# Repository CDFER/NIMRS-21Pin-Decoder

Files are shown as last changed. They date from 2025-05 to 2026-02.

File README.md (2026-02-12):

# NIMRS-21Pin-Decoder

PCB Render

A miniature DCC decoder for model railways featuring an ESP32-S3 microcontroller, designed to fit standard 21-pin sockets. Includes motor control, sound output, and lighting control in a 30x15.5mm footprint (following NMRA spec).

I don't quite have the time to work on this project at the momemnt but Kyle (ProjectInitiative) is starting to work on firmware for this board. You can follow the progress here: [https://github.com/ProjectInitiative/NIMRS-Firmware](https://github.com/ProjectInitiative/NIMRS-Firmware)

## Features

- **Compact Design**: 30mm × 15.5mm × 1.0mm 4-layer PCB
- **Power Management**: Dual TPS63070 buck-boost converters for stable 9V (motor) and 3.3V (logic) supplies
- **Quiet Operation**: DRV8213 motor driver with real-time adjustable off-time current regulation
- **Audio System**: MAX98357A I2S amplifier driving 4-8Ω speaker
- **Wireless Capable**: U.FL antenna connector for ESP32-S3's Wi-Fi
- **DCC Compatibility**: Handles ~15V square wave AC input

## Technical Specifications

### Core Components

- **MCU**: ESP32-S3FN8 (240MHz dual-core, 8MB embedded flash)
- **Motor Driver**: [TI DRV8213](https://www.ti.com/lit/ds/symlink/drv8213.pdf)
- **Audio Amplifier**: [MAX98357A](https://www.analog.com/media/en/technical-documentation/data-sheets/MAX98357A-MAX98357B.pdf)
- **Power Regulation**: Dual [TPS63070](http://www.ti.com/lit/ds/symlink/tps63070.pdf) buck-boost converters

### PCB Stackup

1. Top Layer: Signals with GND pour
2. Inner 1: Full GND plane
3. Inner 2: Signals with 3V3 pour
4. Bottom Layer: GND plane with sparse signals

PCB Layers

## Design Highlights

- Single-sided assembly and 0.3/0.4mm for cost efficiency
- Optimized ground planes for EMI reduction
- Decoupling buck-boost for stable motor PWM operation
- WiFi + BT support with U.FL antenna

## Getting Started

1. Clone the repository:

   ```bash
   git clone https://github.com/CDFER/NIMRS-21Pin-Decoder.git
   ```

2. Open in KiCad v9.0+
3. Review design files:
   - [Interactive PCB Viewer](https://kicanvas.org/?github=https%3A%2F%2Fgithub.com%2FCDFER%2FNIMRS-21Pin-Decoder)
   - [Schematic](Images/Schematic.avif)
   - [PCB Layout](Images/PCB-All-Layers.avif)

## Repository Structure

```
├── Custom_Footprints.pretty  # Custom component footprints
├── Datasheets               # Component technical documents
├── Images                   # PCB visuals and renders
├── LICENSE
└── README.md
```

For those wondering the 21-Pin decoder socket uses a 1.27mm, 22Pin back entry connector and I am using the ```BD050-22-A-0-0500-L-D``` from GCT (the CAD file, footprint and symbol can be found in the custom footprints library I have made).

Top View

## License

MIT License - See [LICENSE](LICENSE) for details.

## Contributing

Pull requests welcome! Please discuss major changes via issues first.

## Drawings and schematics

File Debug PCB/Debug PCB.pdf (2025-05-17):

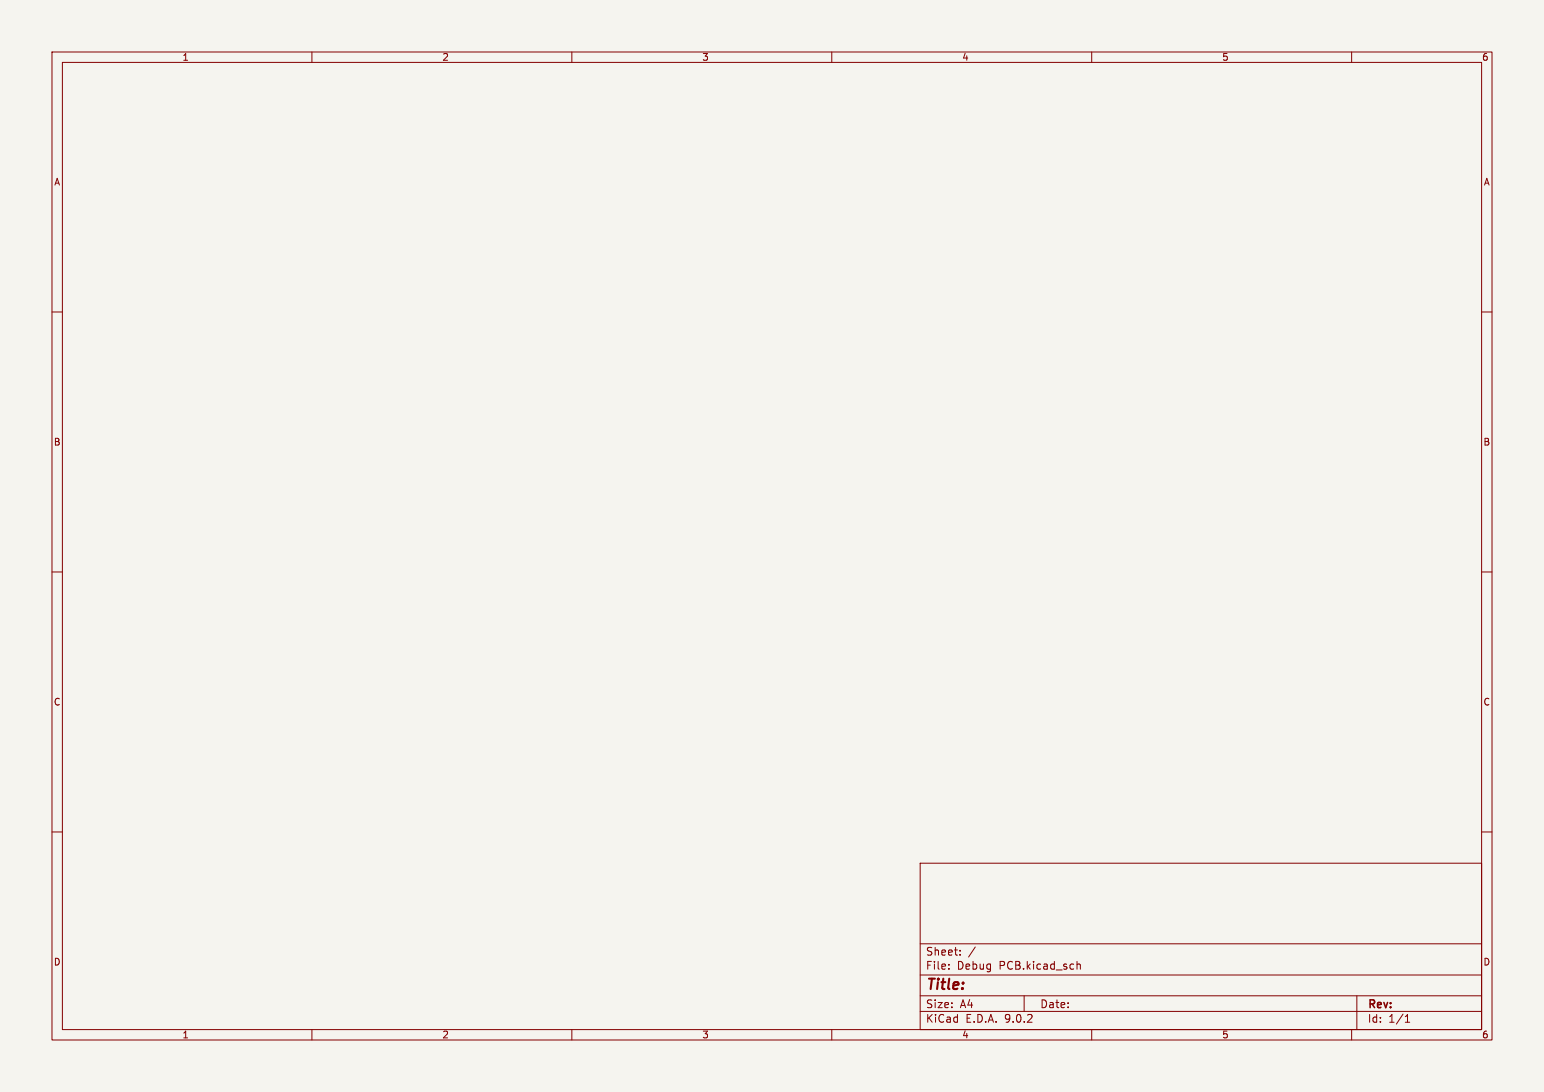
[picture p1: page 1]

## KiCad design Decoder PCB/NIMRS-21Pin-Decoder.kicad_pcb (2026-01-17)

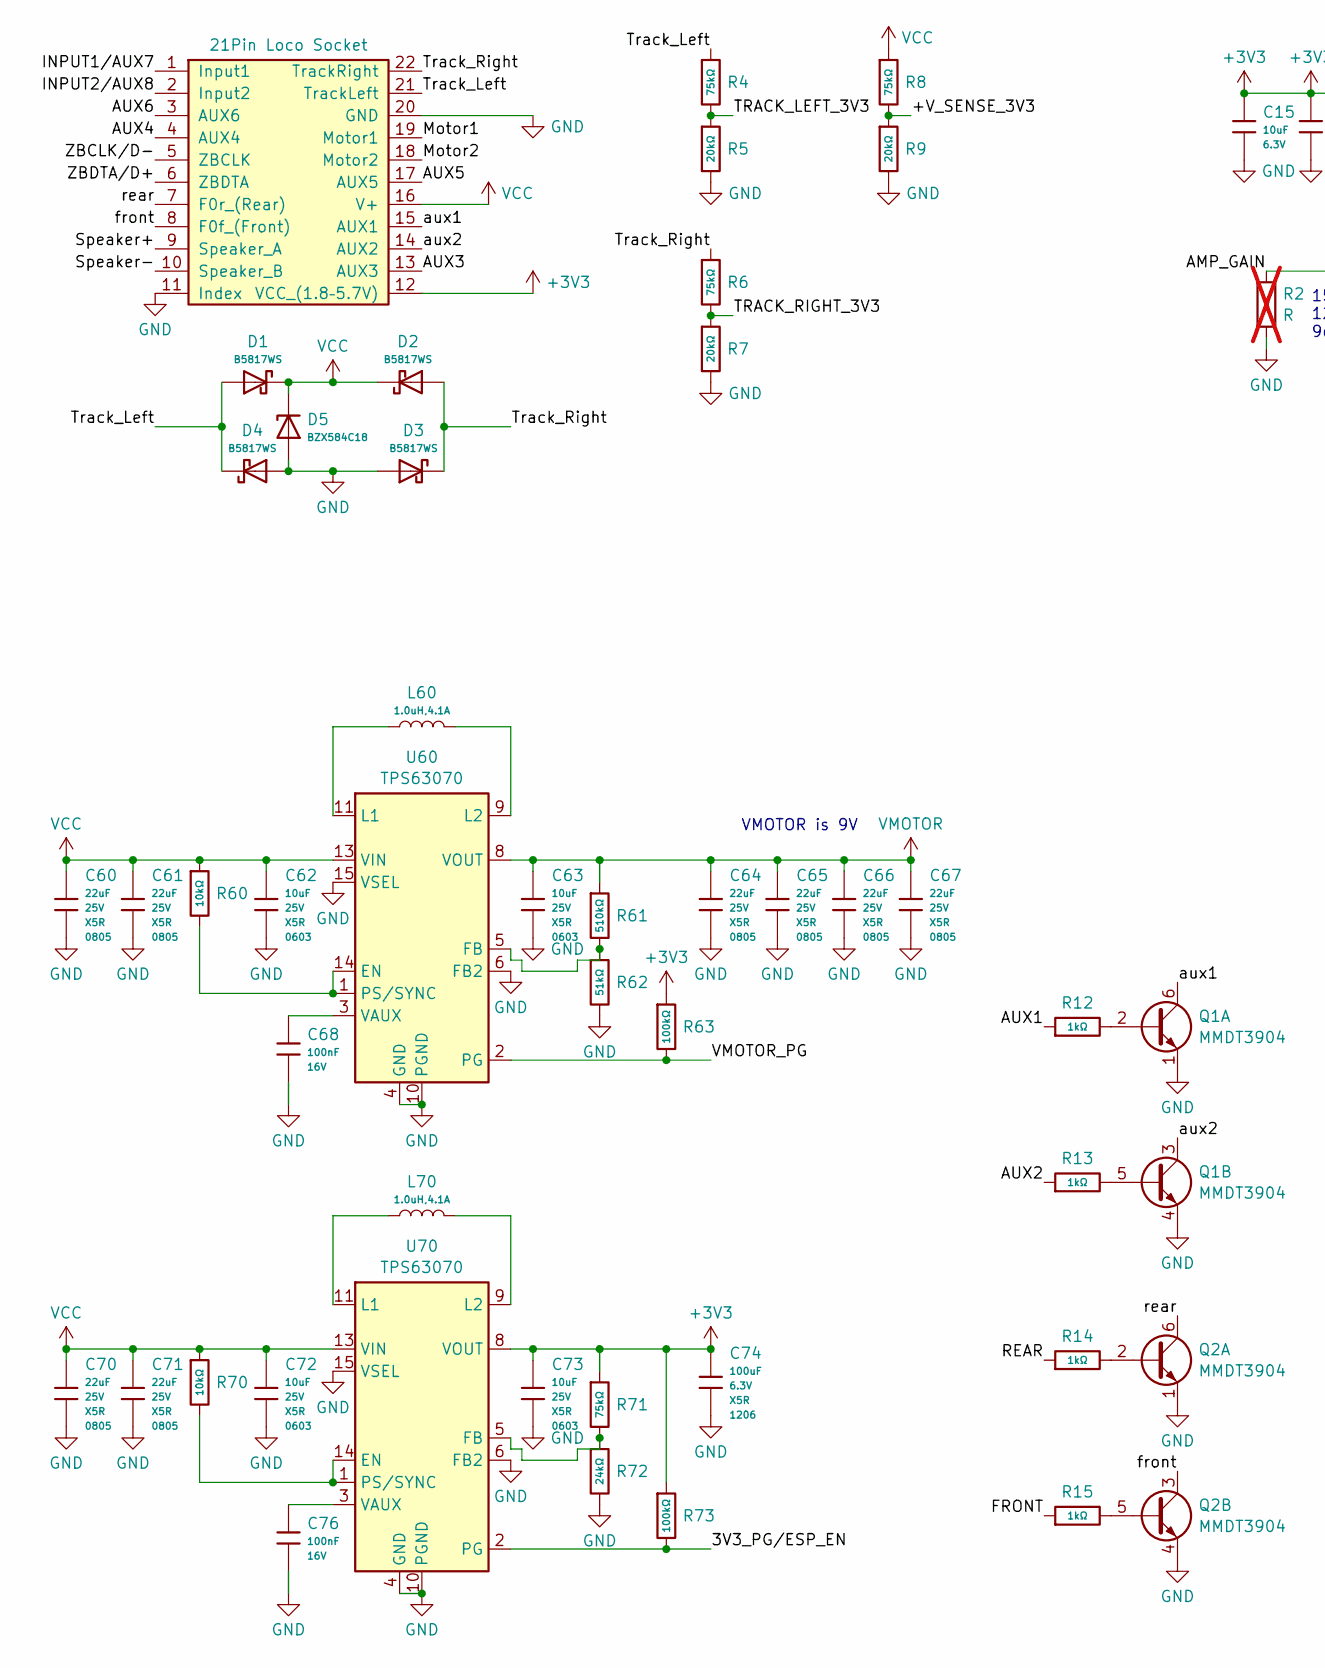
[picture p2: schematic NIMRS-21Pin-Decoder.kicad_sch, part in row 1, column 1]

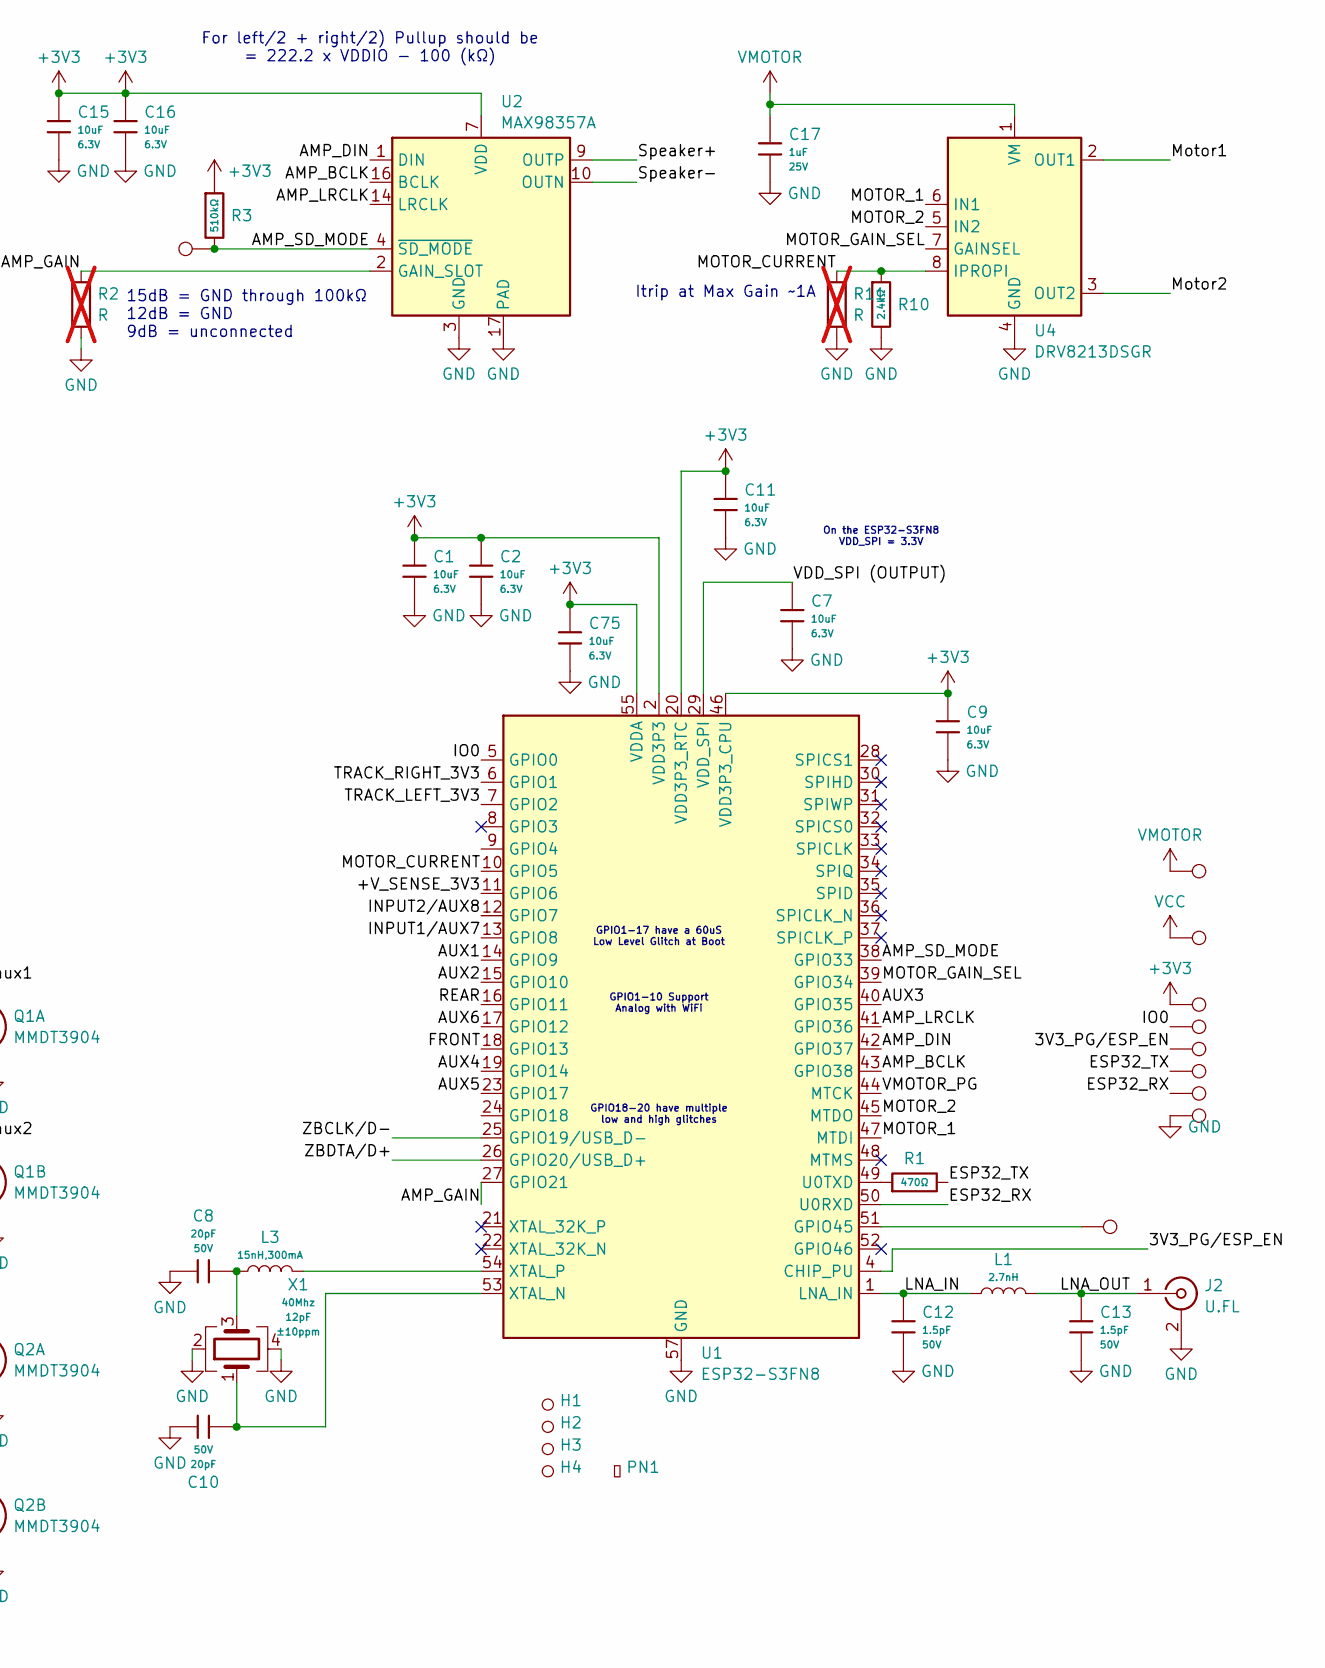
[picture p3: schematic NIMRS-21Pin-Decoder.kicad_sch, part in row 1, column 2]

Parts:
C1, C2, C7, C9, C11, C15, C16, C75: 10uF; C_0402; Voltage Rated 6.3V; Tolerance ±20%; Part CL05A106MQ5NUNC; LCSC C15525
C8, C10: 20pF; C_0402; Voltage Rated 50V; Tolerance ±5%; Part 0402CG200J500NT; LCSC C1554
C12, C13: 1.5pF; C_0402; Voltage Rated 50V; Part 0402CG1R5C500NT; LCSC C1552
C17: 1uF; C_0402; Voltage Rated 25V; Tolerance ±10%; Part CL05A105KA5NQNC; LCSC C52923
C60, C61, C64, C65, C66, C67, C70, C71: 22uF; C_0805; Voltage Rated 25V; Tolerance ±20%; Part CL21A226MAQNNNE; LCSC C45783
C62, C63, C72, C73: 10uF; C_0603; Voltage Rated 25V; Tolerance ±20%; Part CL10A106MA8NRNC; LCSC C96446
C68, C76: 100nF; C_0402; Voltage Rated 16V; Tolerance ±10%; Part CL05B104KO5NNNC; LCSC C1525
C74: 100uF; C_1206; Voltage Rated 6.3V; Tolerance ±20%; Part CL31A107MQHNNNE; LCSC C15008
D1, D2, D3, D4: B5817WS; D_SOD-323; Forward Voltage (Vf@If) 450mV@1.0A; Reverse Voltage (Vr) 20V; Part B5817WS; LCSC C7420329
D5: BZX584C18; D_SOD-523; Part BZX584C18; LCSC C22395581
H1, H2, H3, H4: Hole_Tooling_JLCPCB
J1: 21Pin Loco Socket; BD050-22-A-0-0500-L-D; LCSC C7219764
J2: U.FL; IPEX-SMD_BWIPX-1-001E; LCSC C5137195
L1: 2.7nH; L_0402; Part LQG15HS2N7S02D; LCSC C77108
L3: 15nH,300mA; L_0402; Tolerance ±5%; Part SDCL1005C15NJTDF; LCSC C27143
L60, L70: 1.0uH,4.1A; IND-SMD_L2.0-W1.6-B; Tolerance ±20%; Part FTC201610S1R0MBCA; LCSC C5832342
PN1: Part_Num_JLCPCB
Q1, Q2: MMDT3904; SOT-363_SC-70-6; Part MMDT3904; LCSC C41375125
R1: 470Ω; R_0402; Overload Voltage (Max) 50V; Tolerance ±1%; Part 0402WGF4700TCE; LCSC C25117
R2, R11: R; R_0805_2012Metric_Pad1.20x1.40mm_HandSolder; not fitted
R3, R61: 510kΩ; R_0402; Overload Voltage (Max) 50V; Tolerance ±1%; Part 0402WGF5103TCE; LCSC C11616
R4, R6, R8, R71: 75kΩ; R_0402; Overload Voltage (Max) 50V; Tolerance ±1%; Part 0402WGF7502TCE; LCSC C25798
R5, R7, R9: 20kΩ; R_0402; Overload Voltage (Max) 50V; Tolerance ±1%; Part 0402WGF2002TCE; LCSC C25765
R10: 2.4kΩ; R_0402; Overload Voltage (Max) 50V; Tolerance ±1%; Part 0402WGF2401TCE; LCSC C25882
R12, R13, R14, R15: 1kΩ; R_0402; Overload Voltage (Max) 50V; Tolerance ±1%; Part 0402WGF1001TCE; LCSC C11702
R60, R70: 10kΩ; R_0402; Overload Voltage (Max) 50V; Tolerance ±1%; Part 0402WGF1002TCE; LCSC C25744
R62: 51kΩ; R_0402; Overload Voltage (Max) 50V; Tolerance ±1%; Part 0402WGF5102TCE; LCSC C25794
R63, R73: 100kΩ; R_0402; Overload Voltage (Max) 50V; Tolerance ±1%; Part 0402WGF1003TCE; LCSC C25741
R72: 24kΩ; R_0402; Overload Voltage (Max) 50V; Tolerance ±1%; Part 0402WGF2402TCE; LCSC C25769
TP1, TP2, TP3, TP4, TP5, TP6, TP7, TP8, TP9, TP10: Test Point; TestPoint_Pad_D1.0mm
U1: ESP32-S3FN8; QFN-56-1EP_7x7mm_P0.4mm_EP4x4mm_ThermalVias; LCSC C2913196
U2: MAX98357A; TQFN-16-1EP_3x3mm_P0.5mm_EP1.23x1.23mm; LCSC C910544
U4: DRV8213DSGR; WSON-8-1EP_2x2mm_P0.5mm_EP0.9x1.6mm; LCSC C22407186
U60, U70: TPS63070; RNM0015A; LCSC C109322
X1: 40Mhz; Crystal_SMD_2016-4Pin_2.0x1.6mm; Tolerance ±10ppm; LCSC C20885029

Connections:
+3V3: C1.1, C2.1, C9.1, C11.1, C15.1, C16.1, C73.1, C74.1, C75.1, J1.12 (VCC_(1.8–5.7V)), R3.1, R63.1, R71.1, R73.1, TP2.1, U1.2 (VDD3P3), U1.3 (VDD3P3), U1.20 (VDD3P3_RTC), U1.46 (VDD3P3_CPU), U1.55 (VDDA), U1.56 (VDDA), U2.7 (VDD), U2.8 (VDD), U70.8 (VOUT)
/3V3_PG/ESP_EN: R73.2, TP3.1, U1.4 (CHIP_PU), U70.2 (PG)
/+V_SENSE_3V3: R8.2, R9.1, U1.11 (GPIO6)
/AMP_BCLK: U1.43 (GPIO38), U2.16 (BCLK)
/AMP_DIN: U1.42 (GPIO37), U2.1 (DIN)
/AMP_GAIN: R2.1, U1.27 (GPIO21), U2.2 (GAIN_SLOT)
/AMP_LRCLK: U1.41 (GPIO36), U2.14 (LRCLK)
/AMP_SD_MODE: R3.2, TP8.1, U1.38 (GPIO33), U2.4 (~SD_MODE)
/AUX1: R12.1, U1.14 (GPIO9)
/AUX2: R13.1, U1.15 (GPIO10)
/AUX3: J1.13 (AUX3), U1.40 (GPIO35)
/AUX4: J1.4 (AUX4), U1.19 (GPIO14)
/AUX5: J1.17 (AUX5), U1.23 (GPIO17)
/AUX6: J1.3 (AUX6), U1.17 (GPIO12)
/ESP32_RX: TP5.1, U1.50 (U0RXD)
/ESP32_TX: R1.2, TP4.1
/FRONT: R15.1, U1.18 (GPIO13)
/INPUT1/AUX7: J1.1 (Input1), U1.13 (GPIO8)
/INPUT2/AUX8: J1.2 (Input2), U1.12 (GPIO7)
/IO0: TP1.1, U1.5 (GPIO0)
/LNA_IN: C12.1, L1.1, U1.1 (LNA_IN)
/LNA_OUT: C13.1, J2.1 (In), L1.2
/MOTOR_1: U1.47 (MTDI), U4.6 (IN1)
/MOTOR_2: U1.45 (MTDO), U4.5 (IN2)
/MOTOR_CURRENT: R10.1, R11.1, U1.10 (GPIO5), U4.8 (IPROPI)
/MOTOR_GAIN_SEL: U1.39 (GPIO34), U4.7 (GAINSEL)
/Motor1: J1.19 (Motor1), U4.2 (OUT1)
/Motor2: J1.18 (Motor2), U4.3 (OUT2)
/REAR: R14.1, U1.16 (GPIO11)
/Speaker+: J1.9 (Speaker_A), U2.9 (OUTP)
/Speaker-: J1.10 (Speaker_B), U2.10 (OUTN)
/TRACK_LEFT_3V3: R4.2, R5.1, U1.7 (GPIO2)
/TRACK_RIGHT_3V3: R6.2, R7.1, U1.6 (GPIO1)
/Track_Left: D1.2, D4.1, J1.21 (TrackLeft), R4.1
/Track_Right: D2.2, D3.1, J1.22 (TrackRight), R6.1
/VDD_SPI (OUTPUT): C7.1, U1.29 (VDD_SPI)
/VMOTOR_PG: R63.2, U1.44 (MTCK), U60.2 (PG)
/ZBCLK/D-: J1.5 (ZBCLK), U1.25 (GPIO19/USB_D-)
/ZBDTA/D+: J1.6 (ZBDTA), U1.26 (GPIO20/USB_D+)
/aux1: J1.15 (AUX1), Q1.6 (C1)
/aux2: J1.14 (AUX2), Q1.3 (C2)
/front: J1.8 (F0f_(Front)), Q2.3 (C2)
/rear: J1.7 (F0r_(Rear)), Q2.6 (C1)
GND: C1.2, C2.2, C7.2, C8.1, C9.2, C10.1, C11.2, C12.2, C13.2, C15.2, C16.2, C17.2, C60.2, C61.2, C62.2, C63.2, C64.2, C65.2, C66.2, C67.2, C68.2, C70.2, C71.2, C72.2, C73.2, C74.2, C75.2, C76.2, D3.2, D4.2, D5.2, J1.11 (Index), J1.20 (GND), J2.2 (Ext), J2.3 (Ext), Q1.1 (E1), Q1.4 (E2), Q2.1 (E1), Q2.4 (E2), R2.2, R5.2, R7.2, R9.2, R10.2, R11.2, R62.2, R72.2, TP6.1, U1.57 (GND), U2.3 (GND), U2.11 (GND), U2.15 (GND), U2.17 (PAD), U4.4 (GND), U4.9 (GND), U60.4 (GND), U60.6 (FB2), U60.10 (PGND), U60.15 (VSEL), U70.4 (GND), U70.6 (FB2), U70.10 (PGND), U70.15 (VSEL), X1.2, X1.4
unnamed: C8.2, L3.1, X1.3
unnamed: Q1.2 (B1), R12.2
unnamed: Q1.5 (B2), R13.2
unnamed: Q2.2 (B1), R14.2
unnamed: Q2.5 (B2), R15.2
unnamed: TP7.1, U1.51 (GPIO45)
unnamed: R1.1, U1.49 (U0TXD)
unnamed: C10.2, U1.53 (XTAL_N), X1.1
unnamed: L3.2, U1.54 (XTAL_P)
unnamed: R60.2, U60.1 (PS/SYNC), U60.14 (EN)
unnamed: R61.2, R62.1, U60.5 (FB)
unnamed: L60.1, U60.11 (L1)
unnamed: L60.2, U60.9 (L2)
unnamed: C68.1, U60.3 (VAUX)
unnamed: R70.2, U70.1 (PS/SYNC), U70.14 (EN)
unnamed: R71.2, R72.1, U70.5 (FB)
unnamed: L70.1, U70.11 (L1)
unnamed: L70.2, U70.9 (L2)
unnamed: C76.1, U70.3 (VAUX)
VCC: C60.1, C61.1, C62.1, C70.1, C71.1, C72.1, D1.1, D2.1, D5.1, J1.16 (V+), R8.1, R60.1, R70.1, TP9.1, U60.13 (VIN), U70.13 (VIN)
VMOTOR: C17.1, C63.1, C64.1, C65.1, C66.1, C67.1, R61.1, TP10.1, U4.1 (VM), U60.8 (VOUT)

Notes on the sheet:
For left/2 + right/2) Pullup should be = 222.2 x VDDIO - 100 (kΩ)
VMOTOR is 9V
15dB = GND through 100kΩ 12dB = GND 9dB = unconnected
GPIO18-20 have multiple low and high glitches
GPIO1-17 have a 60uS Low Level Glitch at Boot
On the ESP32-S3FN8 VDD_SPI = 3.3V
GPIO1-10 Support Analog with WiFi
Itrip at Max Gain ~1A

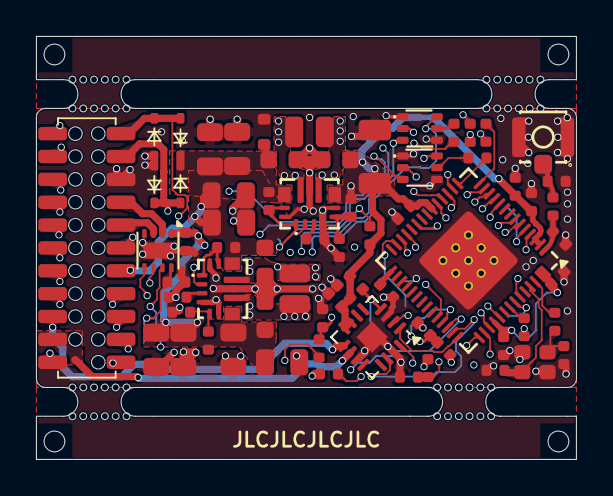
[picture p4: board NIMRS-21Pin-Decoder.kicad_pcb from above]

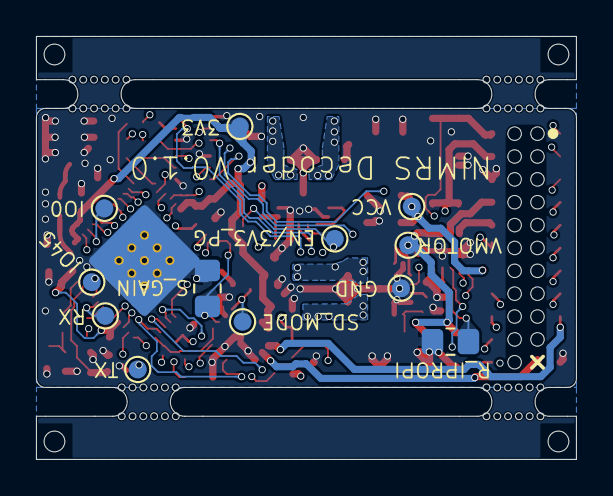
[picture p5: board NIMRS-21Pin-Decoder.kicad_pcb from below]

Board: 4 copper layers, 30.0 x 23.5 mm, 85 parts (12 on the bottom side), 65 nets.

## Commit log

2025-05-11 PCB Checkpoint
    [NIMRS-21Pin-Decoder.kicad_pcb, NIMRS-21Pin-Decoder.kicad_sch]
2025-05-12 PCB RC1
    [JLCPCB_Rotations.csv, NIMRS-21Pin-Decoder.kicad_pcb, NIMRS-21Pin-Decoder.kicad_sch]
2025-05-12 Center PCB, Tidy up for r/PrintedCurcuitBoard
    [NIMRS-21Pin-Decoder.kicad_pcb, NIMRS-21Pin-Decoder.kicad_sch]
2025-05-17 Restructure and PCB layout fine tuning
    [Debug PCB.kicad_pcb, Debug PCB.kicad_sch, JLCPCB_Rotations.csv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]
2025-05-29 Add alternative 21-pin socket
    [NIMRS-21Pin-Decoder.kicad_pcb]
2026-01-17 Add extra test points
    [NIMRS-21Pin-Decoder.kicad_pcb, NIMRS-21Pin-Decoder.kicad_sch]

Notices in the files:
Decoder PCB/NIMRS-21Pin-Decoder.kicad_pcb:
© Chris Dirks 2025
